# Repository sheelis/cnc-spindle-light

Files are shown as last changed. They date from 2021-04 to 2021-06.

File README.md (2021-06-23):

# Circular LED strip PCB for CNC spindle light

This is a PCB and spindle attachment design and software to light up the CNC work area from all sides in any color or sequence desired (as long as you can program it to). The LED control is done by FastLED library, so it's not too hard to create your own sequences.

There is also an option to insert 2 lasers at 90* difference from each other in order to produce a cross shape on XY plane exactly where the tool will touch the work piece. Lasers have their own connectors and on/off switch on the PCB.
There is also a provision for attaching the the Z probe to the pcb, but it is only tested on my own DIY CNC.

You will find here:
- Firmware for ATTiny85
- PCB design
- Spindle mount design

## Final result

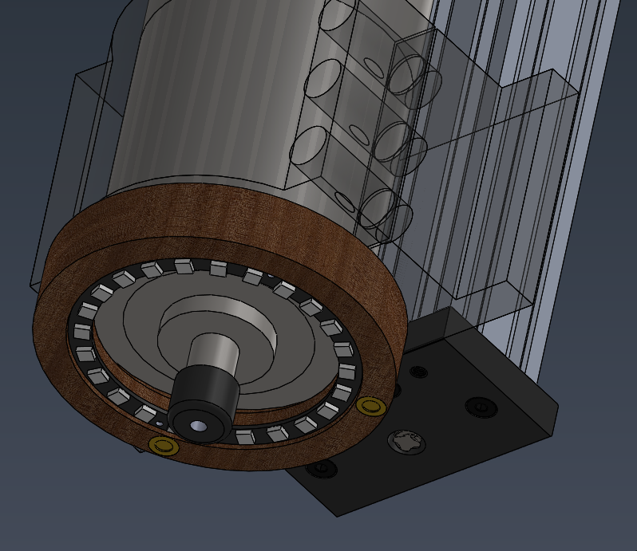
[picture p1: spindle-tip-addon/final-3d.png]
Final 3d image
  

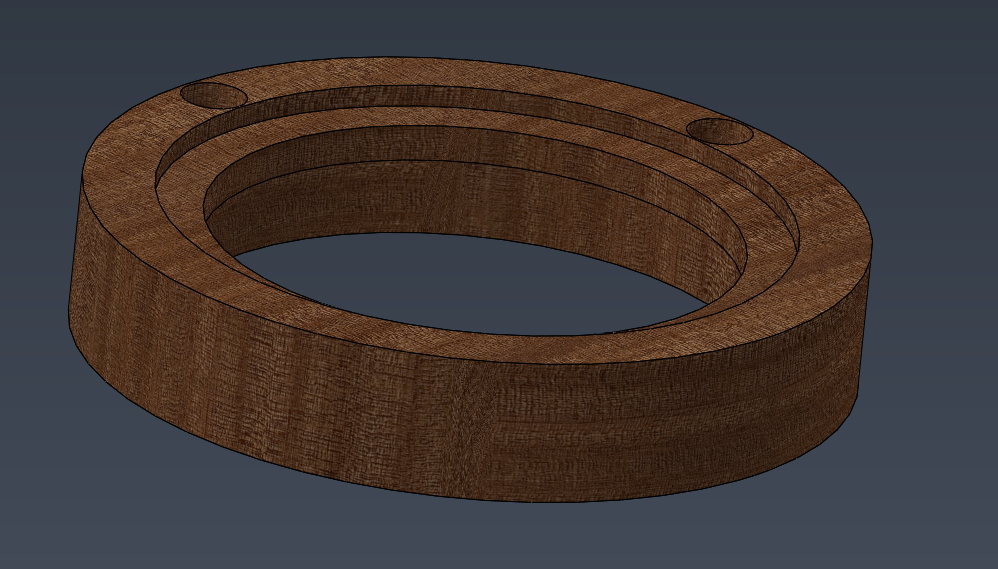
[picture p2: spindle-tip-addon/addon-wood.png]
Wooden mount
  

Then milled the wooden mount and attached the LED ring and lasers. I did not insert the lasers fully because later i will need to rotate them to align with center.

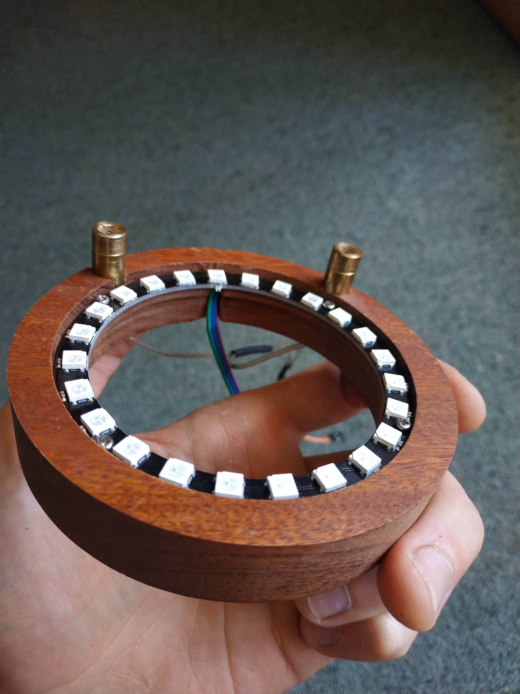
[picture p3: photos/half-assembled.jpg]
milled and assembled mount with lights
  

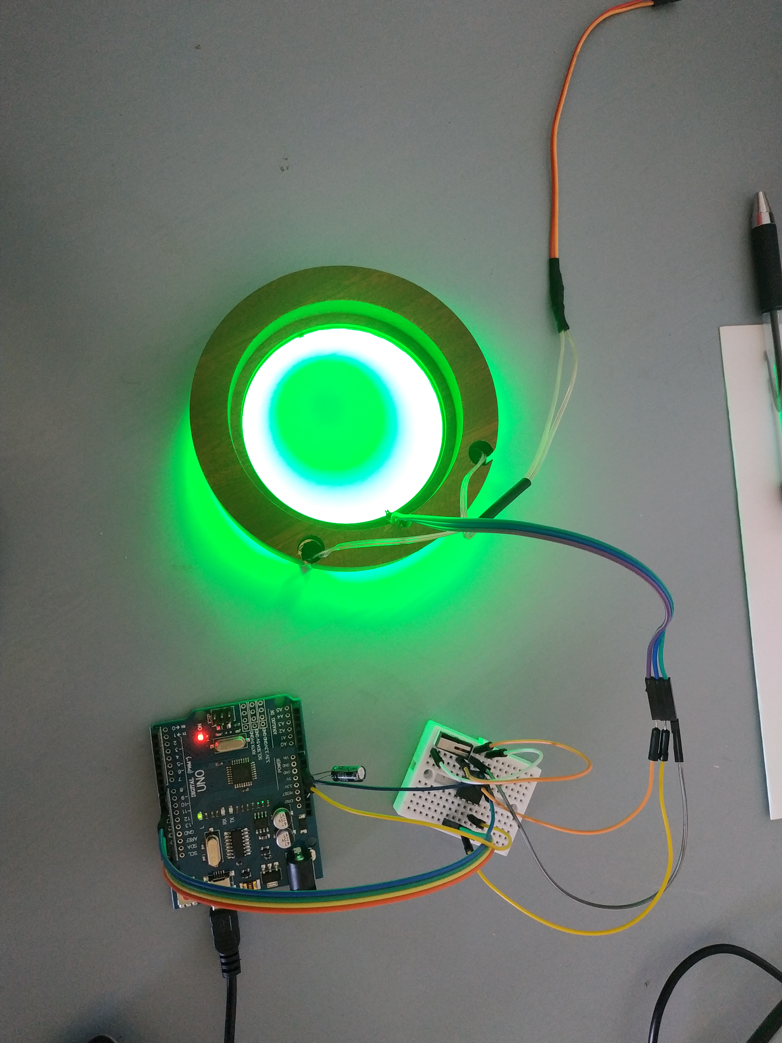
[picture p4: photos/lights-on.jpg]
light powered by ATTiny
  

The mounting holes on the PCB align with any 20mm increment profiles such as my 2080 C-beam

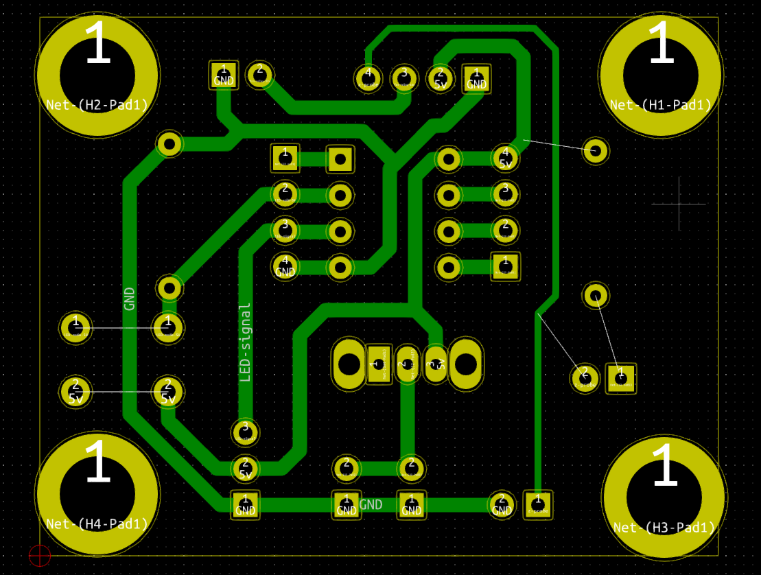
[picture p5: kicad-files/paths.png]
PCB
  

PCB milled with a 0.2mm HSS bit

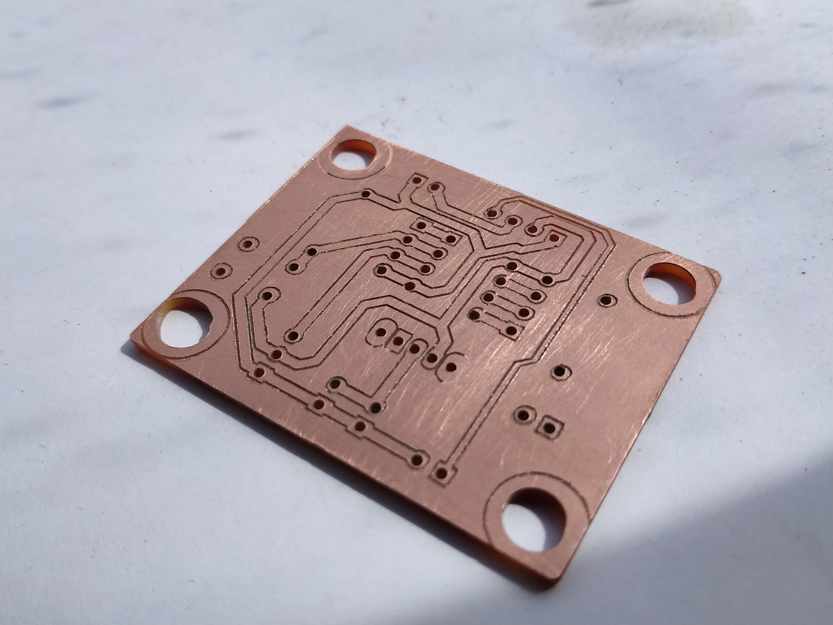
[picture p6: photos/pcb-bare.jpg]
PCB milled
  

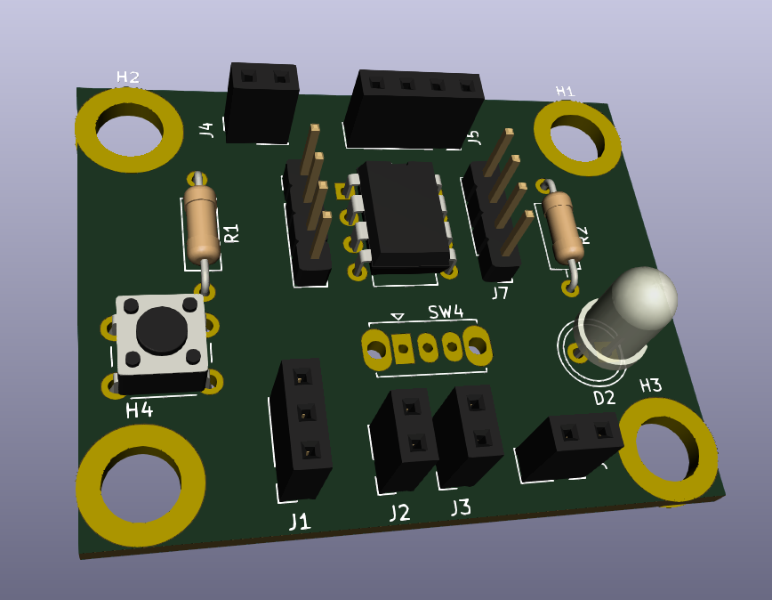
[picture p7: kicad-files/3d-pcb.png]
PCB 3d view
 

And the assembled PCB

## Parts list

This project requires:
- 1x WS2812B LED strip (circular, 24 LEDs)
- 1x ATTiny85
- 2x line or cross lasers
- 1x button and 1x switch
- some 2.54mm headers and sockets
- 2x THT resistors (10K)
- 1x single-sided copper board
- wooden block for milling the mount from
- 1x arduino uno (only for programming the ATTiny85)

## Usage

1. Mill or 3D print the mount.
2. Mill or etch the PCB at home or get it done by a PCB factory.
3. Upload the firmware to ATTiny85 using your preferred method. I used an arduino UNO as ISP.
4. Solder on all the components (I suggest starting with the smallest ones)
5. Connect the 5v power and LED strip to PCB
6. Press the button to change the LED mode

PM me for questions and comments!

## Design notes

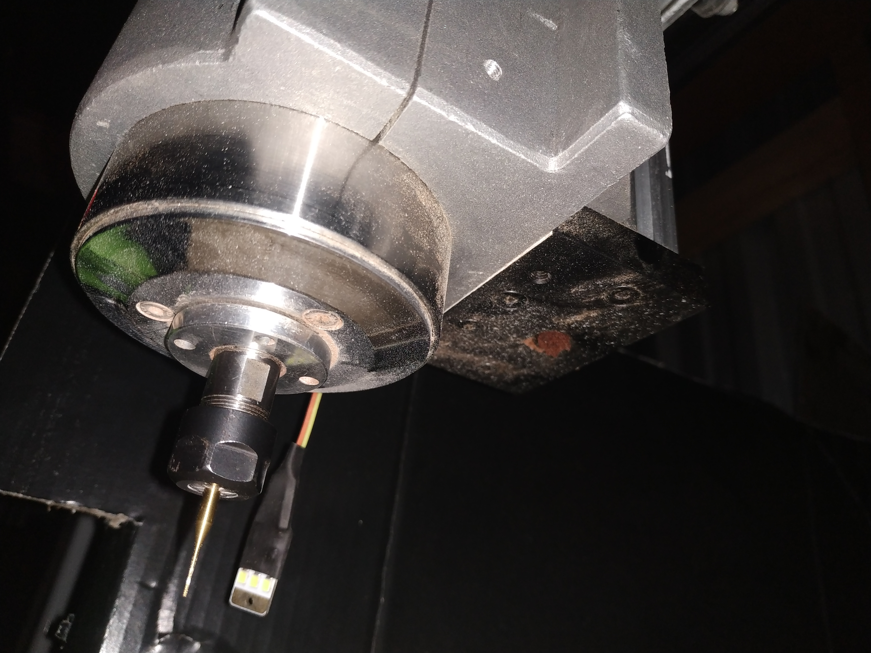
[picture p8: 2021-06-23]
photos/spindle-bottom.jpg

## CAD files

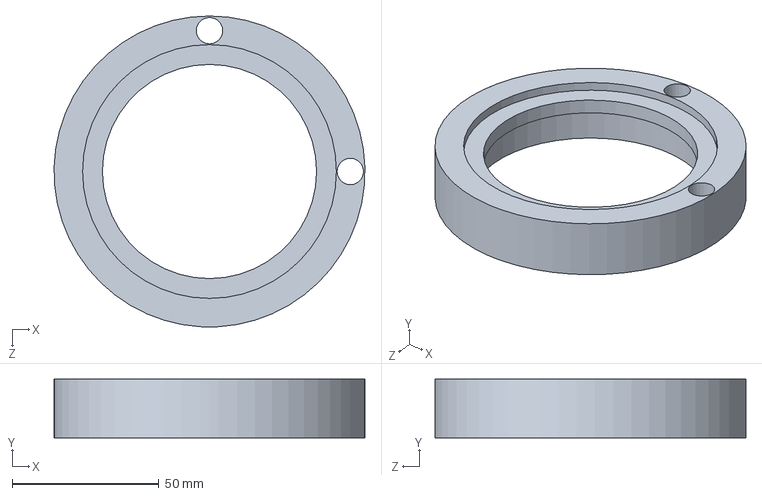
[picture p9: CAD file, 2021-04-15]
spindle-tip-addon/spindle-tip-addon.SLDPRT
106.0 x 20.0 x 106.0 mm

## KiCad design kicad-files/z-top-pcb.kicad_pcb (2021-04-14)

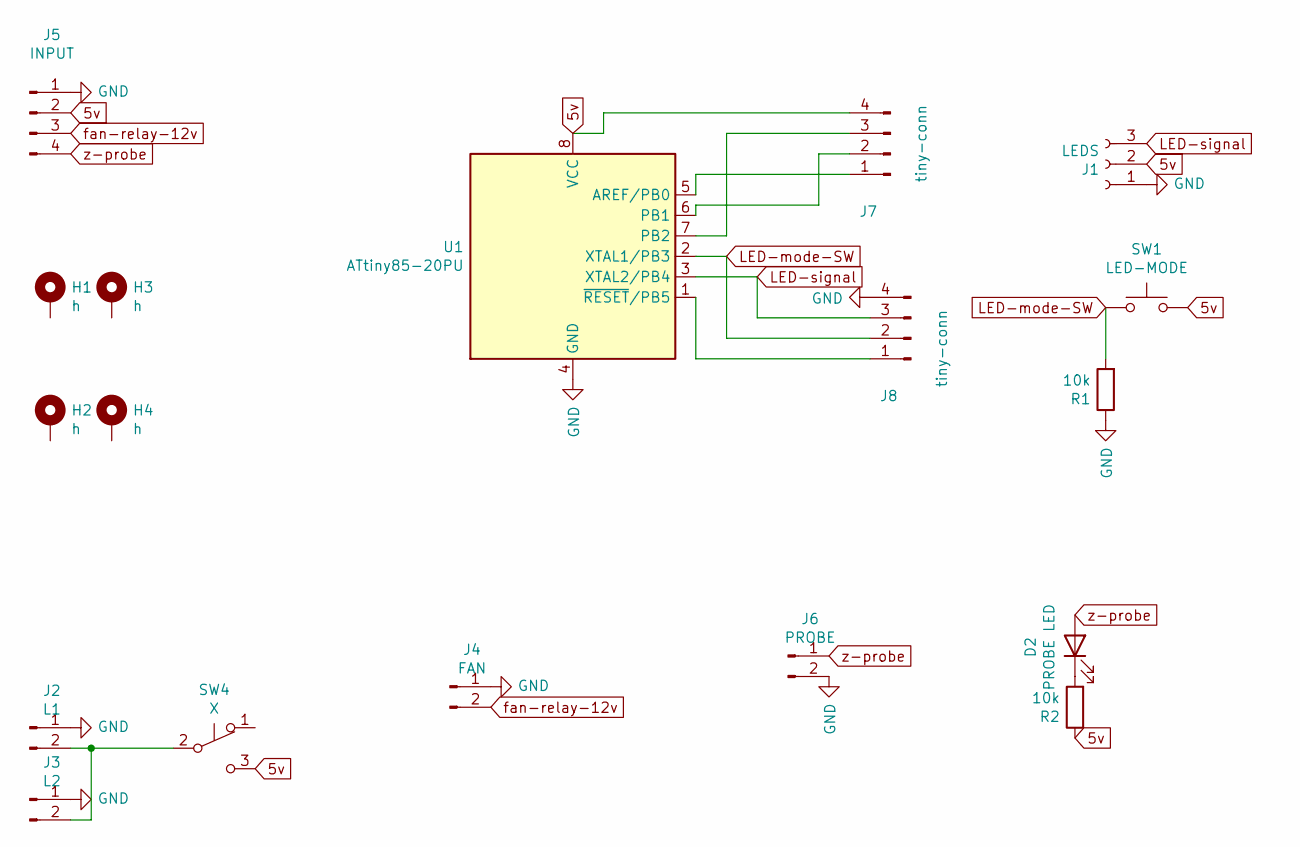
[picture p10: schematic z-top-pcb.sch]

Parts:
D2: PROBE LED; LED_D5.0mm_Clear
H1, H2, H3, H4: h; MountingHole_5.3mm_M5_ISO14580_Pad
J1: LEDS; PinSocket_1x03_P2.54mm_Vertical
J2: L1; PinSocket_1x02_P2.54mm_Vertical
J3: L2; PinSocket_1x02_P2.54mm_Vertical
J4: FAN; PinSocket_1x02_P2.54mm_Vertical
J5: INPUT; PinSocket_1x04_P2.54mm_Vertical
J6: PROBE; PinSocket_1x02_P2.54mm_Vertical
J7, J8: tiny-conn; PinHeader_1x04_P2.54mm_Vertical
R1, R2: 10k; R_Axial_DIN0207_L6.3mm_D2.5mm_P10.16mm_Horizontal
SW1: LED-MODE; SW_PUSH_6mm
SW4: X; SW_Slide_1P2T_CK_OS102011MS2Q
U1: ATtiny85-20PU; DIP-8_W7.62mm

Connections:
5v: J1.2, J5.2, J7.4, R2.1, SW1.2, SW4.3 (C), U1.8 (VCC)
GND: J1.1, J2.1, J3.1, J4.1, J5.1, J6.2, J8.4, R1.1, U1.4 (GND)
LED-mode-SW: J8.2, R1.2, SW1.1, U1.2 (XTAL1/PB3)
LED-signal: J1.3, J8.3, U1.3 (XTAL2/PB4)
unnamed: D2.1 (K), R2.2
unnamed: J2.2, J3.2, SW4.2 (B)
unnamed: J7.1, U1.5 (AREF/PB0)
unnamed: J7.2, U1.6 (PB1)
unnamed: J7.3, U1.7 (PB2)
unnamed: J8.1, U1.1 (~RESET~/PB5)
fan-relay-12v: J4.2, J5.3
z-probe: D2.2 (A), J5.4, J6.1

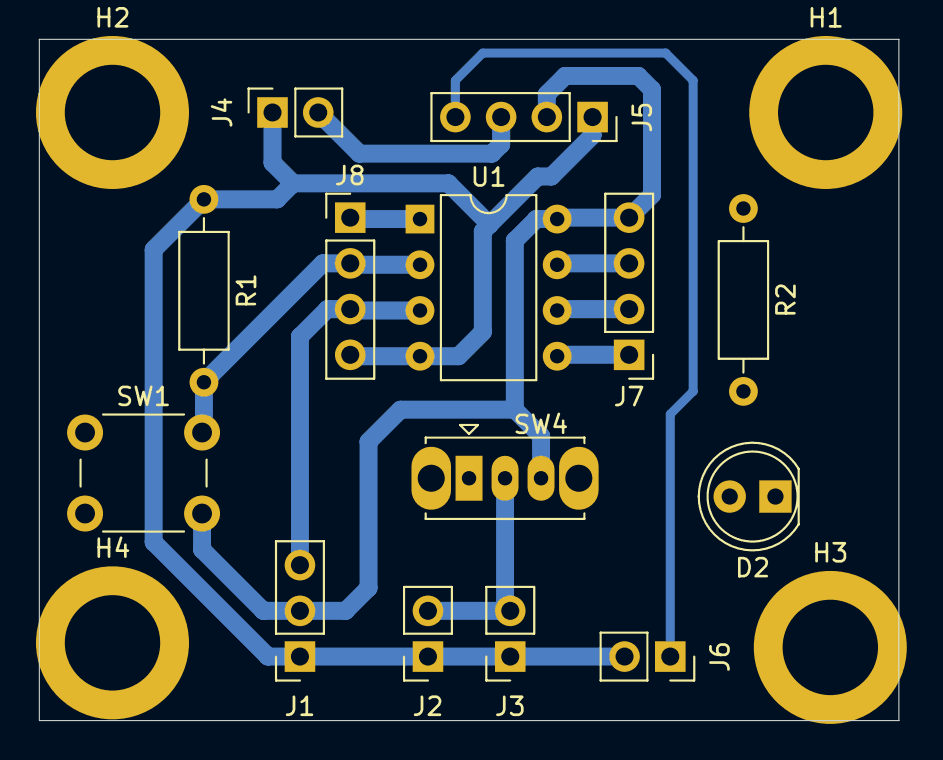
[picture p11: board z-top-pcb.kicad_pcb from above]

Board: 2 copper layers, 47.8 x 37.8 mm, 18 parts (0 on the bottom side), 12 nets.

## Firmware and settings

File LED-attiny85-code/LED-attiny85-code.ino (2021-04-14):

#include <FastLED.h>

#define DATA_PIN 4 // change to Pin 0 for ATTiny
#define BUTTON_PIN 3 // change to Pin 0 for ATTiny
#define NUM_LEDS 24 //24

int button_state = 0;

CRGB strip[NUM_LEDS];
byte mode;

void setup() {
  FastLED.addLeds<WS2812B, DATA_PIN>(strip, NUM_LEDS); // setup the strip
  
}

void loop() {

if (digitalRead(BUTTON_PIN) == HIGH){
  if (button_state < 4){
  button_state++;
  } else {
    button_state = 0;
  }
}

switch (button_state) {
  case 0:
    fill_solid(strip, NUM_LEDS, CRGB::White);
    FastLED.show();
    delay(500);
    break;
  case 1:
    fill_solid(strip, NUM_LEDS, CRGB::Red);
    FastLED.show();
    delay(500);
    break;
  case 2:
    fill_solid(strip, NUM_LEDS, CRGB::Blue);
    FastLED.show();
    delay(500);
    break;
  case 3:
    fill_solid(strip, NUM_LEDS, CRGB::Green);
    FastLED.show();
    delay(500);
    break;
  case 4:
    for (int ld = 0; ld < NUM_LEDS;ld++){ // 1 LED runs around
      fill_solid(strip, NUM_LEDS, CRGB::Black);
      strip[ld] = CRGB::White;
      FastLED.show();
      delay(40);
    }
    break;
  default:
    fill_solid(strip, NUM_LEDS, CRGB::White);
    FastLED.show();
    break;
  }
}

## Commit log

2021-04-15 images and mount model
    [spindle-tip-addon.SLDPRT]
2021-04-15 mount images
2021-04-15 about lasers...
2021-04-15 more on parts and PCB
2021-04-15 about LEDs
